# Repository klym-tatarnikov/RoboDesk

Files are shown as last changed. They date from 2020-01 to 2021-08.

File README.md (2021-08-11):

# RoboDesk
Read LOGICDATA protocol to control height of a powered sit/stand desk.

LOGICDATA protocol decoding from [phord's RoboDesk](https://github.com/phord/RoboDesk/tree/LogicData)

## Current features:
* Double tap a direction to go to a hardcoded target height
* Wifi connection
* MQTT publish/subscribe

## Files:
* `firmware`: platformio code for the d1 mini
* `schematic`: Eagle schematic/board/gerbers

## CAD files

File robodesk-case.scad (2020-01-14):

/*//////////////////////////////////////////////////////////////////
  -    FB Aka Heartman/Hearty 2016     -
  -   http://heartygfx.blogspot.com    -
  -       OpenScad Parametric Box      -
  -         CC BY-NC 3.0 License       -
////////////////////////////////////////////////////////////////////
12/02/2016 - Fixed minor bug
28/02/2016 - Added holes ventilation option
09/03/2016 - Added PCB feet support, fixed the shell artefact on export mode.

 */////////////////////////// - Info - //////////////////////////////

// All coordinates are starting as integrated circuit pins.
// From the top view :

//   CoordD           <---       CoordC
//                                 ^
//                                 ^
//                                 ^
//   CoordA           --->       CoordB


////////////////////////////////////////////////////////////////////


////////// - Paramètres de la boite - Box parameters - /////////////

/* [Box dimensions] */
// - Longueur - Length
Length        = 90;
// - Largeur - Width
Width         = 100;
// - Hauteur - Height
Height        = 50;
// - Epaisseur - Wall thickness
Thick         = 2.5;//[2:5]

/* [Box options] */
// - Diamètre Coin arrondi - Filet diameter
Filet         = 2;//[0.1:12]
// - lissage de l'arrondi - Filet smoothness
Resolution    = 50;//[1:100]
// - Tolérance - Tolerance (Panel/rails gap)
m             = 0.9;
// Pieds PCB - PCB feet (x4)
PCBFeet       = 0;// [0:No, 1:Yes]
// - Decorations to ventilation holes
Vent          = 0;// [0:No, 1:Yes]
// - Decoration-Holes width (in mm)
Vent_width    = 1.5;



/* [PCB_Feet] */
//All dimensions are from the center foot axis

// - Coin bas gauche - Low left corner X position
PCBPosX         = 7;
// - Coin bas gauche - Low left corner Y position
PCBPosY         = 6;
// - Longueur PCB - PCB Length
PCBLength       = 70;
// - Largeur PCB - PCB Width
PCBWidth        = 50;
// - Heuteur pied - Feet height
FootHeight      = 10;
// - Diamètre pied - Foot diameter
FootDia         = 8;
// - Diamètre trou - Hole diameter
FootHole        = 3;


/* [STL element to export] */
//Coque haut - Top shell
TShell          = 0;// [0:No, 1:Yes]
//Coque bas- Bottom shell
BShell          = 0;// [0:No, 1:Yes]
//Panneau avant - Front panel
FPanL           = 1;// [0:No, 1:Yes]
//Panneau arrière - Back panel
BPanL           = 0;// [0:No, 1:Yes]



/* [Hidden] */
// - Couleur coque - Shell color
Couleur1        = "Orange";
// - Couleur panneaux - Panels color
Couleur2        = "OrangeRed";
// Thick X 2 - making decorations thicker if it is a vent to make sure they go through shell
Dec_Thick       = Vent ? Thick*2 : Thick;
// - Depth decoration
Dec_size        = Vent ? Thick*2 : 0.8;





/////////// - Boitier générique bord arrondis - Generic rounded box - //////////

module RoundBox($a=Length, $b=Width, $c=Height){// Cube bords arrondis
    $fn=Resolution;
    translate([0,Filet,Filet]){
        minkowski (){
            cube ([$a-(Length/2),$b-(2*Filet),$c-(2*Filet)], center = false);
            rotate([0,90,0]){
                cylinder(r=Filet,h=Length/2, center = false);
            }
        }
    }
}// End of RoundBox Module


////////////////////////////////// - Module Coque/Shell - //////////////////////////////////

module Coque(){//Coque - Shell
    Thick = Thick*2;
    difference(){
        difference(){//sides decoration
            union(){
                difference() {//soustraction de la forme centrale - Substraction Fileted box

                    difference(){//soustraction cube median - Median cube slicer
                        union() {//union
                            difference(){//Coque
                                RoundBox();
                                translate([Thick/2,Thick/2,Thick/2]){
                                    RoundBox($a=Length-Thick, $b=Width-Thick, $c=Height-Thick);
                                }
                            }//Fin diff Coque
                            difference(){//largeur Rails
                                translate([Thick+m,Thick/2,Thick/2]){// Rails
                                    RoundBox($a=Length-((2*Thick)+(2*m)), $b=Width-Thick, $c=Height-(Thick*2));
                                }//fin Rails
                                translate([((Thick+m/2)*1.55),Thick/2,Thick/2+0.1]){ // +0.1 added to avoid the artefact
                                    RoundBox($a=Length-((Thick*3)+2*m), $b=Width-Thick, $c=Height-Thick);
                                }
                            }//Fin largeur Rails
                        }//Fin union
                        translate([-Thick,-Thick,Height/2]){// Cube à soustraire
                            cube ([Length+100, Width+100, Height], center=false);
                        }
                    }//fin soustraction cube median - End Median cube slicer
                    translate([-Thick/2,Thick,Thick]){// Forme de soustraction centrale
                        RoundBox($a=Length+Thick, $b=Width-Thick*2, $c=Height-Thick);
                    }
                }


                difference(){// wall fixation box legs
                    union(){
                        translate([3*Thick +5,Thick,Height/2]){
                            rotate([90,0,0]){
                                $fn=6;
                                cylinder(d=16,Thick/2);
                            }
                        }

                        translate([Length-((3*Thick)+5),Thick,Height/2]){
                            rotate([90,0,0]){
                                $fn=6;
                                cylinder(d=16,Thick/2);
                            }
                        }

                    }
                    translate([4,Thick+Filet,Height/2-57]){
                        rotate([45,0,0]){
                            cube([Length,40,40]);
                        }
                    }
                    translate([0,-(Thick*1.46),Height/2]){
                        cube([Length,Thick*2,10]);
                    }
                } //Fin fixation box legs
            }

            union(){// outbox sides decorations

                for(i=[0:Thick:Length/4]){

                    // Ventilation holes part code submitted by Ettie - Thanks ;)
                    translate([10+i,-Dec_Thick+Dec_size,1]){
                        cube([Vent_width,Dec_Thick,Height/4]);
                    }
                    translate([(Length-10) - i,-Dec_Thick+Dec_size,1]){
                        cube([Vent_width,Dec_Thick,Height/4]);
                    }
                    translate([(Length-10) - i,Width-Dec_size,1]){
                        cube([Vent_width,Dec_Thick,Height/4]);
                    }
                    translate([10+i,Width-Dec_size,1]){
                        cube([Vent_width,Dec_Thick,Height/4]);
                    }


                }// fin de for
                // }
        }//fin union decoration
    }//fin difference decoration


    union(){ //sides holes
        $fn=50;
        translate([3*Thick+5,20,Height/2+4]){
            rotate([90,0,0]){
                cylinder(d=2,20);
            }
        }
        translate([Length-((3*Thick)+5),20,Height/2+4]){
            rotate([90,0,0]){
                cylinder(d=2,20);
            }
        }
        translate([3*Thick+5,Width+5,Height/2-4]){
            rotate([90,0,0]){
                cylinder(d=2,20);
            }
        }
        translate([Length-((3*Thick)+5),Width+5,Height/2-4]){
            rotate([90,0,0]){
                cylinder(d=2,20);
            }
        }
    }//fin de sides holes

}//fin de difference holes
}// fin coque

////////////////////////////// - Experiment - ///////////////////////////////////////////





/////////////////////// - Foot with base filet - /////////////////////////////
module foot(FootDia,FootHole,FootHeight){
    Filet=2;
    color(Couleur1)
        translate([0,0,Filet-1.5])
        difference(){

            difference(){
                //translate ([0,0,-Thick]){
                cylinder(d=FootDia+Filet,FootHeight-Thick, $fn=100);
                //}
                rotate_extrude($fn=100){
                    translate([(FootDia+Filet*2)/2,Filet,0]){
                        minkowski(){
                            square(10);
                            circle(Filet, $fn=100);
                        }
                    }
                }
            }
            cylinder(d=FootHole,FootHeight+1, $fn=100);
        }
}// Fin module foot

module Feet(){
    //////////////////// - PCB only visible in the preview mode - /////////////////////
    translate([3*Thick+2,Thick+5,FootHeight+(Thick/2)-0.5]){

        %square ([PCBLength+10,PCBWidth+10]);
        translate([PCBLength/2,PCBWidth/2,0.5]){
            color("Olive")
                %text("PCB", halign="center", valign="center", font="Arial black");
        }
    } // Fin PCB
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

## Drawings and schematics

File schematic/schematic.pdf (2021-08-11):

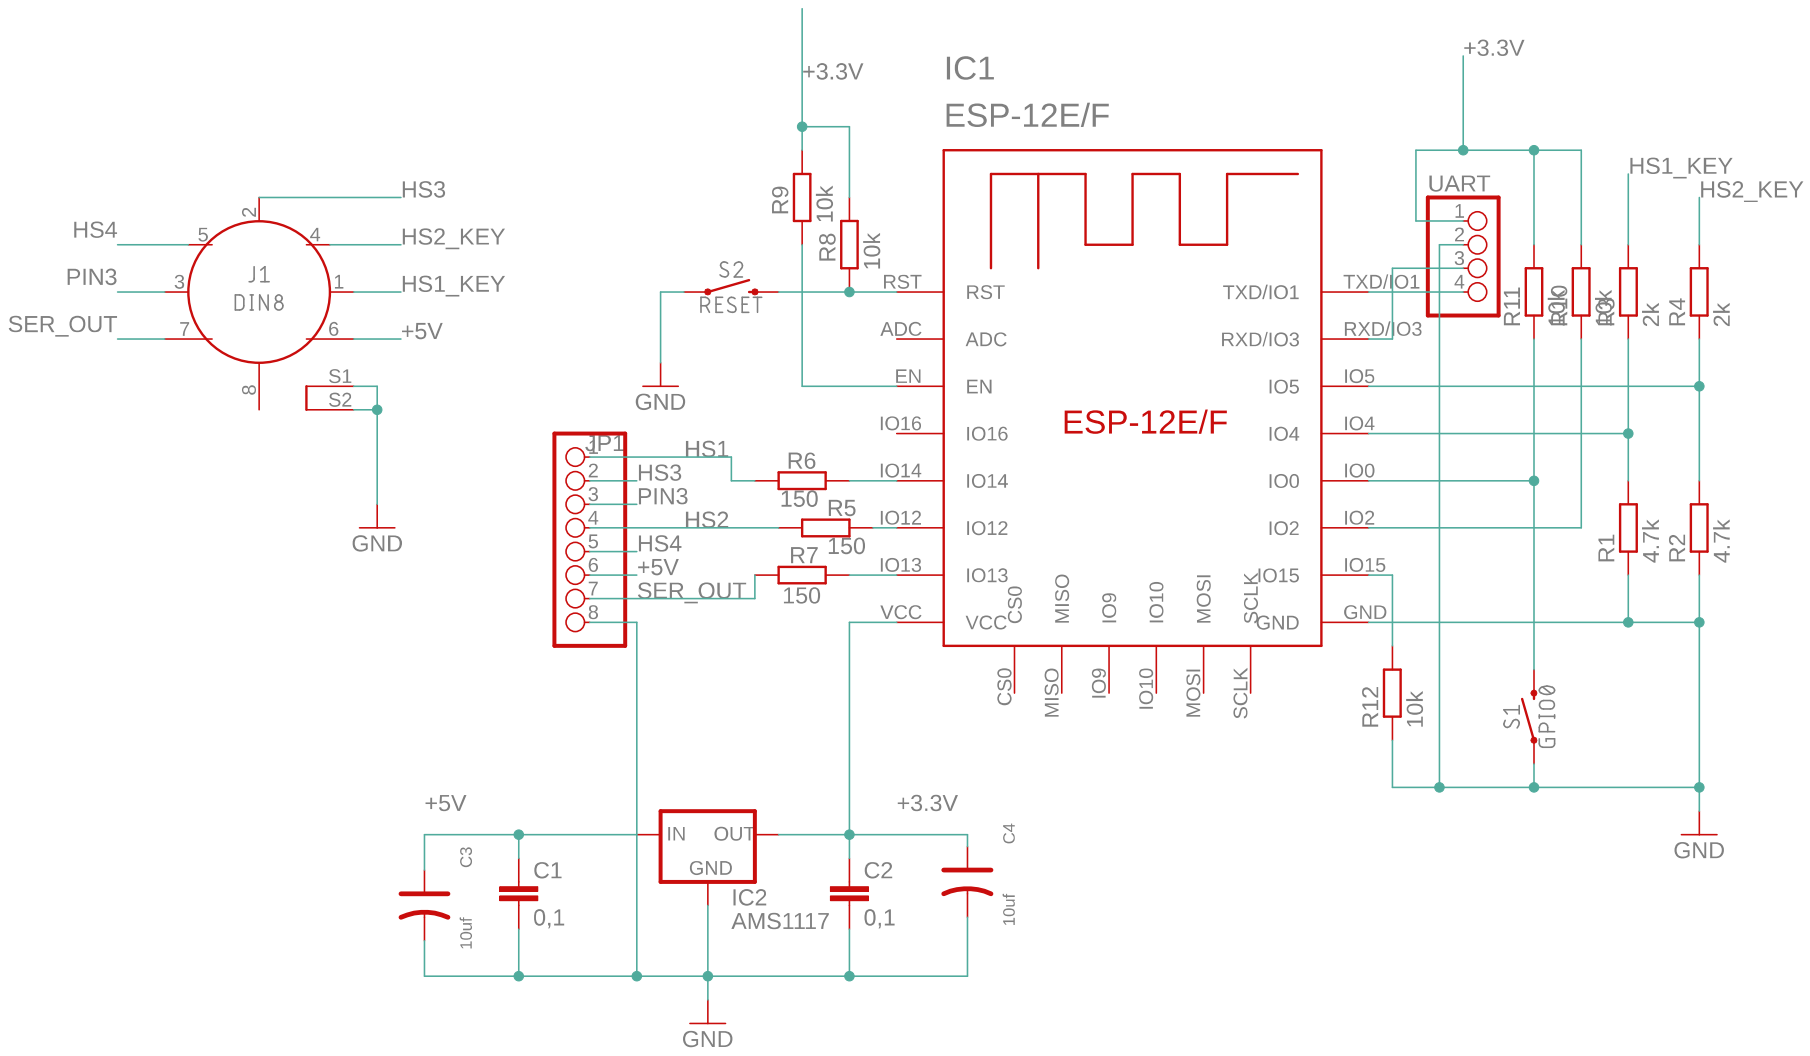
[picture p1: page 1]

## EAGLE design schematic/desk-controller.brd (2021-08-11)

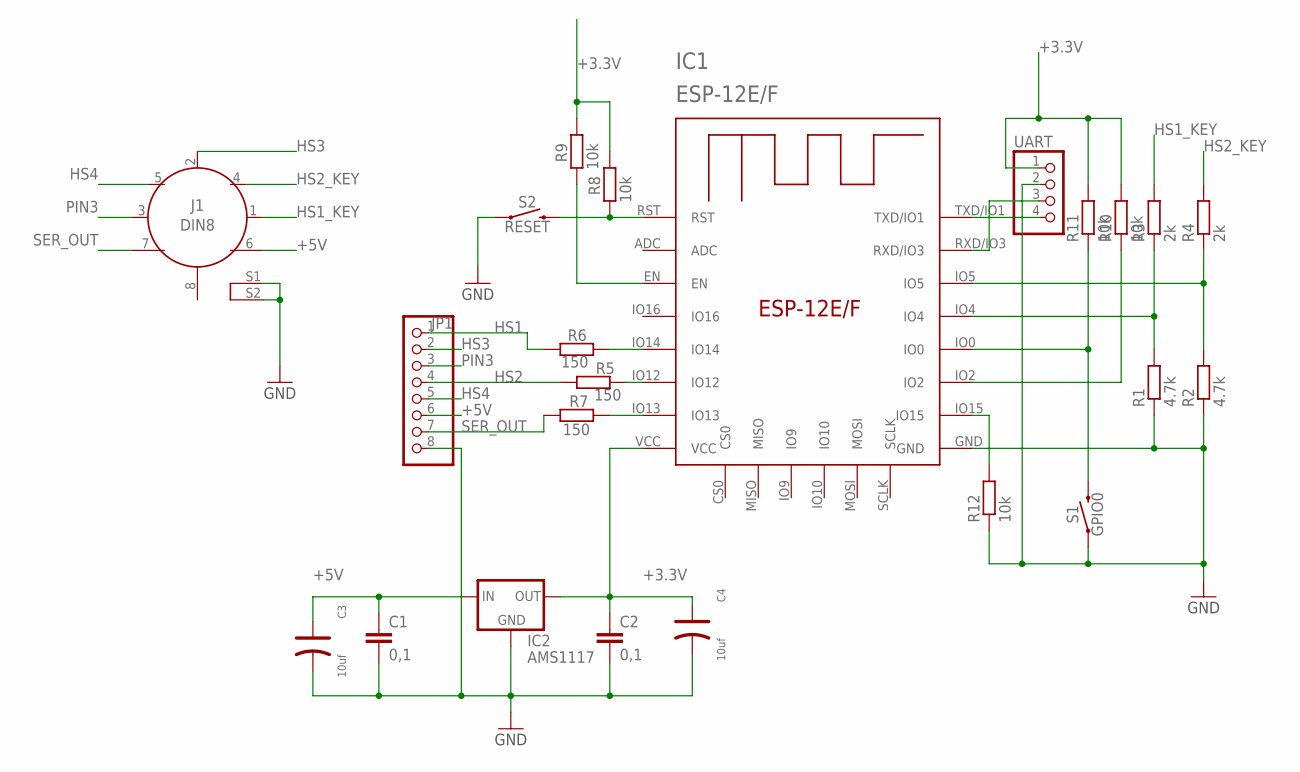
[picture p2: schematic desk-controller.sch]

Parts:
C1, C2: 0,1; C1206
C3, C4: 10uf; AVX-B
IC1: ESP-12E/F; ESP-12E
IC2: AMS1117; SOT223
J1: DIN8; DIN8-RA-PTH
JP1: PINHD-1X8; 1X08
R1, R2: 4.7k; R0805
R3, R4: 2k; R0805
R5, R6, R7: 150; R0805
R8, R9, R10, R11, R12: 10k; R0805
S1: GPIO0; TACTILE_SWITCH_PTH_RIGHT_ANGLE_KIT
S2: RESET; TACTILE_SWITCH_PTH_RIGHT_ANGLE_KIT
UART: PINHD-1X4; 1X04

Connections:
+3.3V: C2.1, C4.+, IC1.VCC, IC2.2 (OUT), R8.1, R9.1, R10.2, R11.2, UART.1
+5V: C1.1, C3.+, IC2.3 (IN), J1.6, JP1.6
GND: C1.2, C2.2, C3.-, C4.-, IC1.GND, IC2.1 (GND), J1.S1 (SHIELD), J1.S2 (SHIELD), JP1.8, R1.1, R2.1, R12.1, S1.1, S2.1, UART.2
HS1: JP1.1, R6.2
HS1_KEY: J1.1, R3.2
HS2: JP1.4, R5.2
HS2_KEY: J1.4, R4.2
HS3: J1.2, JP1.2
HS4: J1.5, JP1.5
unnamed: IC1.IO14, R6.1
unnamed: IC1.IO12, R5.1
unnamed: IC1.IO4, R1.2, R3.1
unnamed: IC1.IO5, R2.2, R4.1
unnamed: IC1.TXD/IO1, UART.4
unnamed: IC1.IO13, R7.1
unnamed: IC1.RST, R8.2, S2.2
unnamed: IC1.EN, R9.2
unnamed: IC1.IO2, R10.1
unnamed: IC1.IO0, R11.1, S1.2
unnamed: IC1.RXD/IO3, UART.3
unnamed: IC1.IO15, R12.2
PIN3: J1.3, JP1.3
SER_OUT: J1.7, JP1.7, R7.2

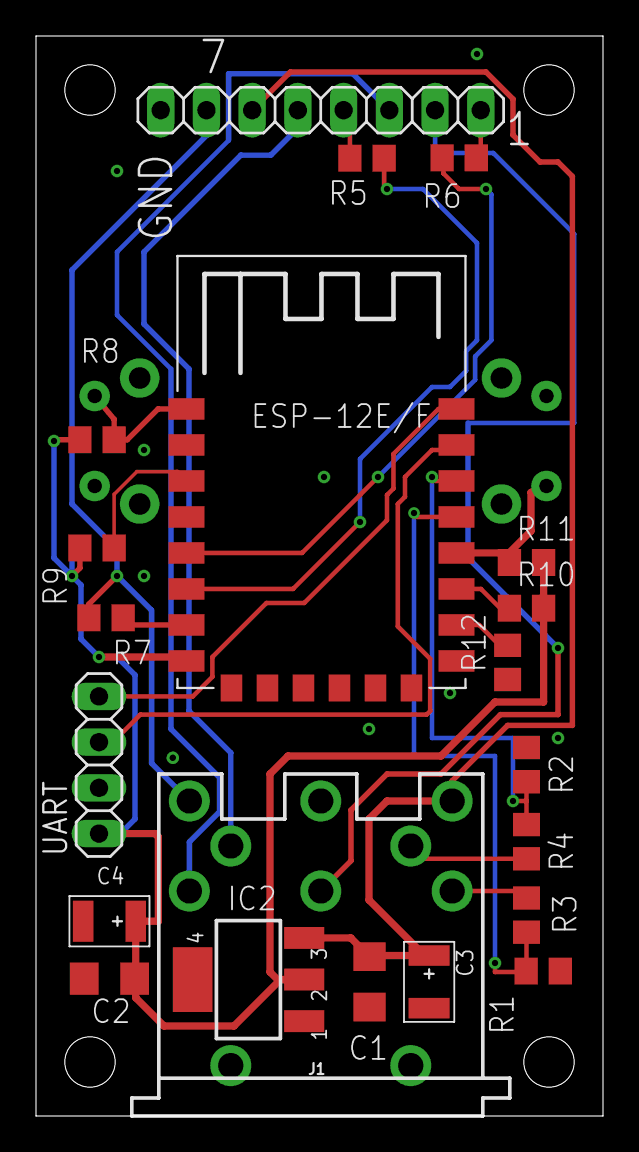
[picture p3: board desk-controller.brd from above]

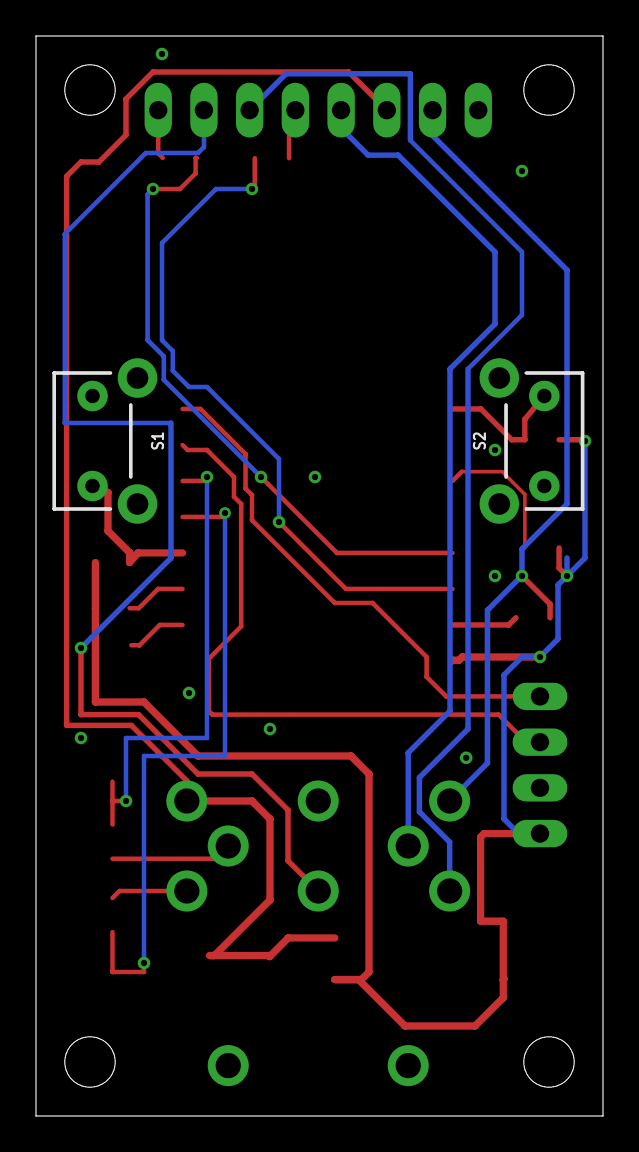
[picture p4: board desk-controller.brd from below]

Board: 2 copper layers, 31.5 x 60.0 mm, 23 parts (2 on the bottom side), 23 nets.

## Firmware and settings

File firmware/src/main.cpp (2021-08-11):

#include <Arduino.h>
#include <ESP8266WiFi.h>
#include <PubSubClient.h>
#include <ArduinoOTA.h>
#include <CREDENTIALS.h>

#include "pins.h"
#include "LogicData.h"


#define ARRAY_SIZE(array) (sizeof(array) / sizeof(array[0]))
#define CYCLE_TIME_US 1000  // 1 ms

int btn_pins[] = {BTN_UP, BTN_DOWN};
const int btn_pressed_state = HIGH;// when we read high, button is pressed
const uint32_t debounce_time = 50;
const uint32_t double_time = 500;

enum Actions { UpSingle, UpDouble, DownSingle, DownDouble };
bool latch_up = false;
bool latch_down = false;

#define BTN_COUNT ARRAY_SIZE(btn_pins)
int8_t btn_last_state[BTN_COUNT] = {-1};
int8_t btn_last_double[BTN_COUNT] = {-1};
uint32_t debounce[BTN_COUNT] = {0};
uint32_t btn_last_on[BTN_COUNT] = {0};


//last_signal is just the last time input was read from buttons or from controller
//If we haven't seen anything from either in a bit, stop moving
uint32_t last_signal = 0;
uint32_t signal_giveup_time = 2000;


LogicData ld(-1);
WiFiClient espClient;
PubSubClient client(espClient);

volatile unsigned long gCurTimeUs = 0;
volatile unsigned long gLastTimeUs = 0;

//-- Buffered mode parses input words and sends them to output separately
void ICACHE_RAM_ATTR logicDataPin_ISR() {
  ld.PinChange(HIGH == digitalRead(LOGICDATA_RX));
}

uint8_t highTarget = 120;
uint8_t lowTarget = 80;

volatile uint8_t height;
uint8_t target;

bool checkTime()
{
    gCurTimeUs = micros();
    if (gCurTimeUs - gLastTimeUs >= CYCLE_TIME_US)
    {
        gLastTimeUs = gCurTimeUs;
        return true;
    }
    return false;
}


void callback(char *topic, byte *payload, unsigned int length)
{
    String receivedtopic = topic;
    int gTargetHeight;

    String value = "";
    for (unsigned int i = 0; i < length; i++)
    {
        value += (char)payload[i];
    }

    if (receivedtopic == "deskcontrol/setheight")
    {
       gTargetHeight = value.toInt();
       if (gTargetHeight>height)
       {
          latch_up = true;
          target = gTargetHeight;
          last_signal = millis();
       }
       if (gTargetHeight<height)
       {
          latch_down = true;
          target = gTargetHeight;
          last_signal = millis();
       }
          
    }
}

void initWiFi()
{
    WiFi.mode(WIFI_STA);
    WiFi.persistent(false);
    WiFi.config(ip, dns, gateway, subnet);
    WiFi.setAutoReconnect(true);
    WiFi.begin(WIFI_SSID, WIFI_PASS); //Connect to the WiFi network
}

void initOTA()
{
    ArduinoOTA.onStart([]() {
        String type;
        if (ArduinoOTA.getCommand() == U_FLASH)
            type = "sketch";
        else // U_SPIFFS
            type = "filesystem";

        // NOTE: if updating SPIFFS this would be the place to unmount SPIFFS using SPIFFS.end()
        Serial.println("Start updating " + type);
    });
    ArduinoOTA.onEnd([]() {
        Serial.println("\nEnd");
    });
    ArduinoOTA.onProgress([](unsigned int progress, unsigned int total) {
        Serial.printf("Progress: %u%%\r", (progress / (total / 100)));
    });
    ArduinoOTA.onError([](ota_error_t error) {
        Serial.printf("Error[%u]: ", error);
        if (error == OTA_AUTH_ERROR)
            Serial.println("Auth Failed");
        else if (error == OTA_BEGIN_ERROR)
            Serial.println("Begin Failed");
        else if (error == OTA_CONNECT_ERROR)
            Serial.println("Connect Failed");
        else if (error == OTA_RECEIVE_ERROR)
            Serial.println("Receive Failed");
        else if (error == OTA_END_ERROR)
            Serial.println("End Failed");
    });
    ArduinoOTA.begin();
}

long lastReconnectAttempt = 0;
boolean mqttReconnect()
{
    if (client.connect("DeskClient"))
    {
        client.subscribe("deskcontrol/setheight");
    }
    return client.connected();
}

void initMQTT()
{
    if (!client.connected())
    {
        long now = millis();
        if (now - lastReconnectAttempt > 5000)
        {
            lastReconnectAttempt = now;
            // Attempt to reconnect
            if (mqttReconnect())
            {
                lastReconnectAttempt = 0;
            }
        }
    }
    else
    {
        // Client connected

        client.loop();
    }
}

long lastPublish = 0;
byte lastHeight = 0;
void publishHeight()
{
    long now = millis();
    if (lastHeight != height && now - lastPublish > 5000)
    {
        lastPublish = now;
        lastHeight = height;
        char heightBuffer[3];
        sprintf(heightBuffer, "%d", height);
        client.publish("deskcontrol/currentheight", heightBuffer, true);
    }
}


void setup() {

  pinMode(BTN_UP, INPUT);
  pinMode(BTN_DOWN, INPUT);
  pinMode(LOGICDATA_RX, INPUT);

  pinMode(ASSERT_UP, OUTPUT);
  pinMode(ASSERT_DOWN, OUTPUT);

  Serial.begin(115200);

  logicDataPin_ISR();
  attachInterrupt(digitalPinToInterrupt(LOGICDATA_RX), logicDataPin_ISR, CHANGE);

  ld.Begin();
  initWiFi();
  initOTA();

  client.setServer(mqtt_server, 1883);
  client.setCallback(callback);
  lastReconnectAttempt = 0;
  gLastTimeUs = micros();

  Serial.println("Robodesk v2.1  build: " __DATE__ " " __TIME__);
}

// Record last time the display changed
// sets globals height and last_signal
void check_display() {
  static uint32_t prev = 0;
  uint32_t msg = ld.ReadTrace();
  char buf[80];
  if (msg) {
    uint32_t now = millis();
    sprintf(buf, "%6ums %s: %s", now - prev, ld.MsgType(msg), ld.Decode(msg));
    Serial.println(buf);
    prev=now;
  }

  // Reset idle-activity timer if display number changes or if any other display activity occurs (i.e. display-ON)
  if (ld.IsNumber(msg)) {
    auto new_height = ld.GetNumber(msg);
    if (new_height == height) {
      return;
    }
    height = new_height;
  }
  if (msg)
    last_signal = millis();
}



void transitionState(enum Actions action) {
  switch(action) {
    case UpSingle:
    case DownSingle:
      if (latch_up || latch_down) {
        Serial.println("Breaking latches");
        latch_up = false;
        latch_down = false;
      }
      break;
    case UpDouble:
      latch_up = true;
      target = highTarget;
      Serial.print("Latching UP ");
      Serial.println(target);
      break;
    case DownDouble:
      latch_down = true;
      target = lowTarget;
      Serial.print("Latching Down ");
      Serial.println(target);
      break;
  }
}

void move() {
  //btn_last_state has current buttons pressed
  if(btn_last_state[0] && btn_last_state[1]) {
    //both buttons pressed, do nothing
    //do nothing
  } else if(btn_last_state[0]) {
    digitalWrite(ASSERT_UP, HIGH);
    return;
  } else if(btn_last_state[1]) {
    digitalWrite(ASSERT_DOWN, HIGH);
    return;
  } else if (!latch_up && !latch_down) {
    //if not latch, do nothing
    digitalWrite(ASSERT_UP, LOW);
    digitalWrite(ASSERT_DOWN, LOW);
    return;
  }

  if (latch_up && latch_down) {
    Serial.println("Latch up and latch down set, this is an issue");
    while(true) ;
  }
  if(millis() - last_signal > signal_giveup_time) {
    Serial.println("Haven't seen input in a while, turning everything off for safety");
    digitalWrite(ASSERT_UP, LOW);
    digitalWrite(ASSERT_DOWN, LOW);
    latch_up = false;
    latch_down = false;
    while(true) ;
  }

  if(height != target) {
    //should be moving
    digitalWrite(latch_up ? ASSERT_UP : ASSERT_DOWN, HIGH);
    digitalWrite(!latch_up ? ASSERT_UP : ASSERT_DOWN, LOW);
    return;
  } else {
    //hit target
    digitalWrite(ASSERT_UP, LOW);
    digitalWrite(ASSERT_DOWN, LOW);
    latch_up = false;
    latch_down = false;
    Serial.print("Hit target ");
    Serial.println(target);
    return;
  }
}


void loop() {

  ArduinoOTA.handle();
  initMQTT();

  // sets global height and last_signal from logicdata serial
  check_display();

  for(uint8_t i=0; i < ARRAY_SIZE(btn_pins); ++i) {
    int btn_state = digitalRead(btn_pins[i]);
    if((btn_state == btn_pressed_state) != btn_last_state[i] && millis() - debounce[i] > debounce_time) {
      //change state
      btn_last_state[i] = (btn_state == btn_pressed_state);
      debounce[i] = millis();
      last_signal = debounce[i];

      if(btn_last_state[i]) {
        if(millis() - btn_last_on[i] < double_time) {
          //double press
          Serial.print("double press ");
          Serial.println(i == 0 ? "up" : "down");
          transitionState(i == 0 ? UpDouble : DownDouble);
        } else {
          btn_last_on[i] = debounce[i];
          //single press
          Serial.print("single press ");
          Serial.println(i == 0 ? "up" : "down");
          transitionState(i == 0 ? UpSingle : DownSingle);
        }
      }// endif pressed
    }
  }
  
  move();
  publishHeight();

}

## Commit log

2019-11-27 add schematic
    [desk-schematic.kicad_pcb, desk-schematic.sch]
2020-01-14 feat(schematic): Redo schematic to new design
    [desk-schematic.kicad_pcb, desk-schematic.sch]
2020-01-14 feat(firmware): switch firmware to pio; rewrite buttons
2020-01-14 fix(enclosure): cleanup scad; tweak sizes
    I changed the front hole sizes to fit what I think is correct, but I
    just carved out the holes till they fit on the thing I printed.
    [robodesk-case.scad]
2021-08-11 Added Eagle schematics
    [desk-controller.brd, desk-controller.sch, desk-schematic.kicad_pcb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]

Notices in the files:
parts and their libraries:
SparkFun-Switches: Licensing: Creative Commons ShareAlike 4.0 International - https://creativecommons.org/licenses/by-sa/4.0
